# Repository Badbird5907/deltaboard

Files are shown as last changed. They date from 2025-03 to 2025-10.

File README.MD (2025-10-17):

# Deltaboard

Deltaboard is a TKL mechanical keyboard, directly using the [Keychron K8](https://www.keychron.com/products/keychron-k8-tenkeyless-wireless-mechanical-keyboard) as inspiration.
The hardest part building this project was routing all the switches and components for the RP2040.

[3D Render](https://autode.sk/4qxmMjt)

## Features:
- TKL Layout
- Kailh MX hotswap sockets
- OLED display
- Integrated RP2040
- USB-C
- RGB lighting
- EC11 Encoder
- QMK/VIA firmware

## Screenshots

### Schematic
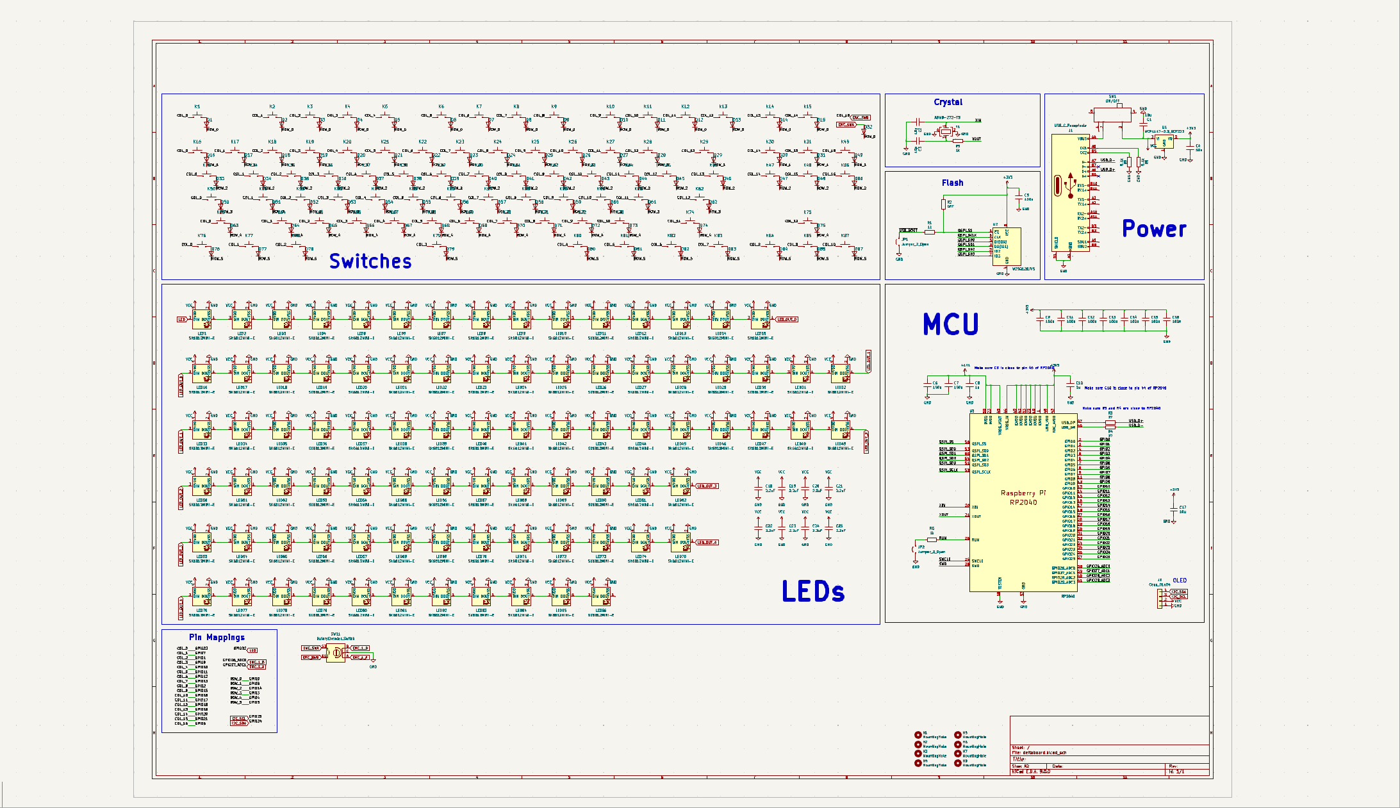
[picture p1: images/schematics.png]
Schematic


### PCB
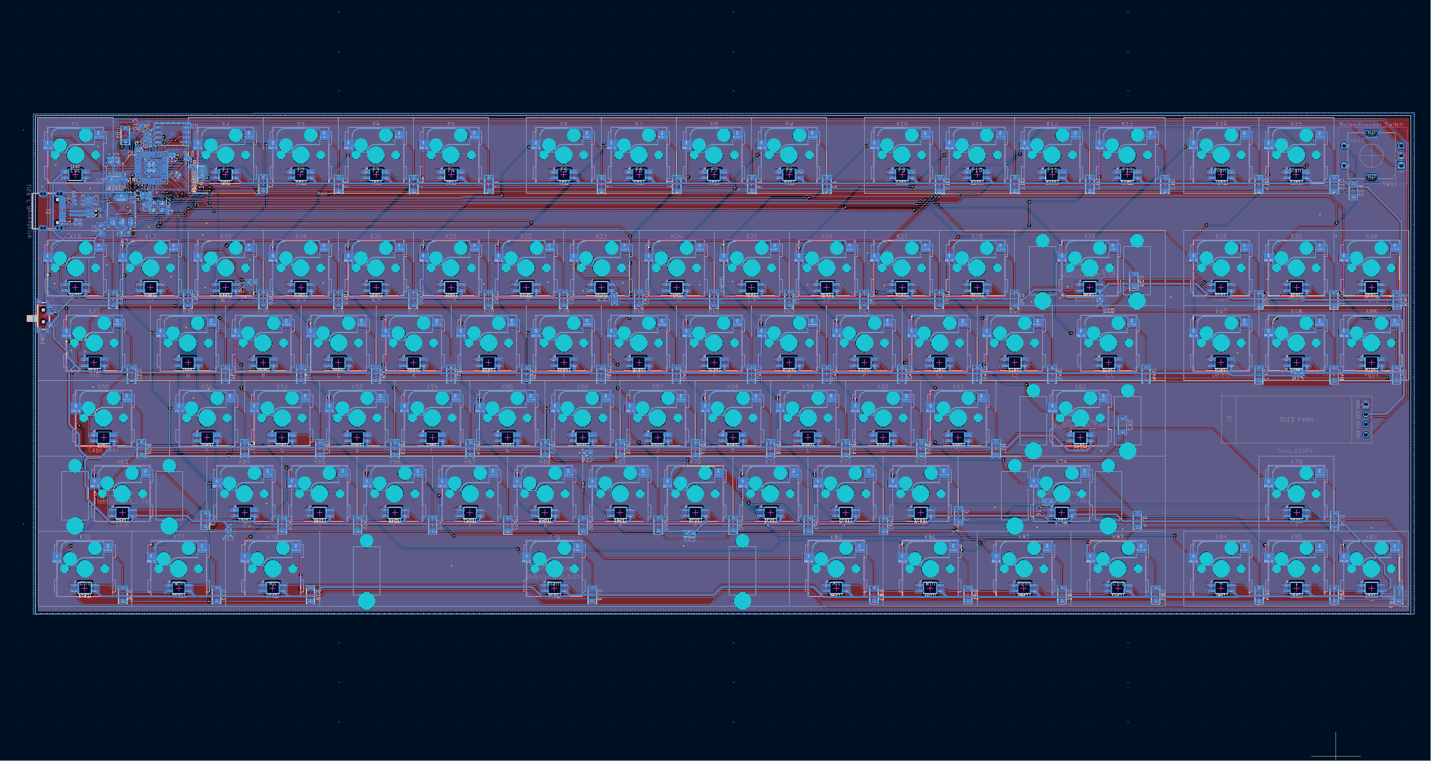
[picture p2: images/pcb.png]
PCB


### Front
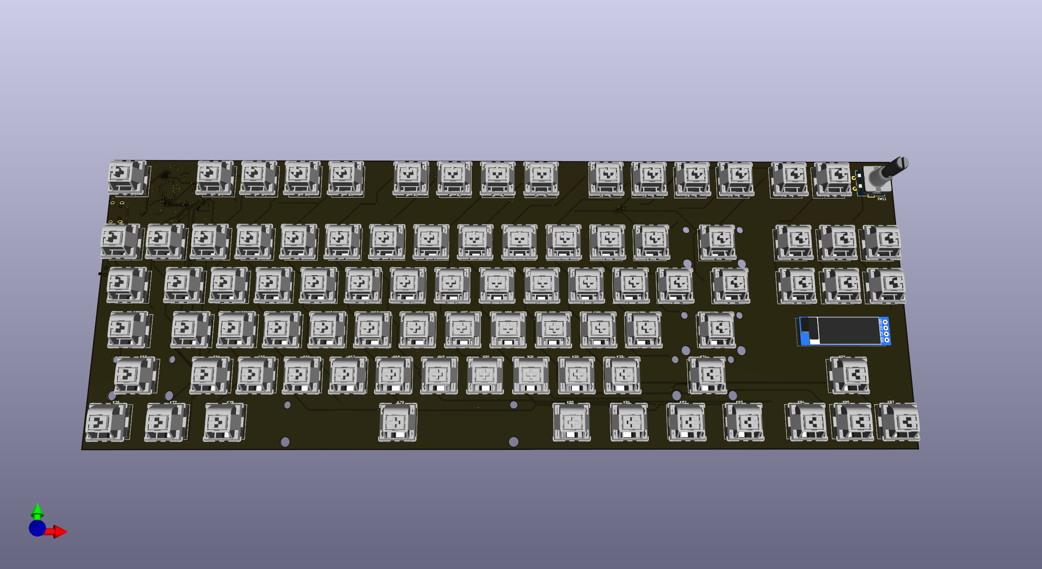
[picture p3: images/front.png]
Front


### Back
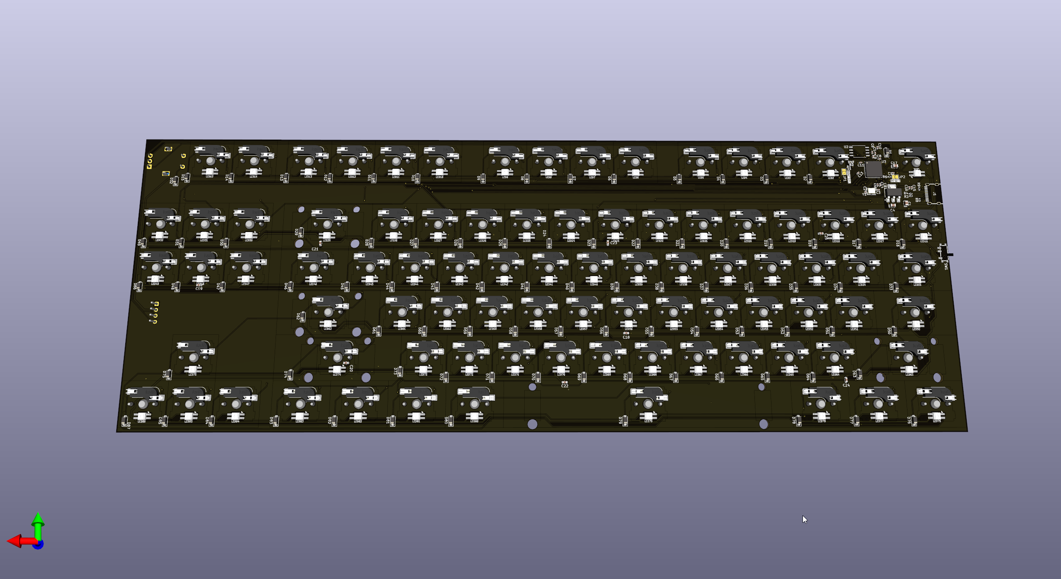
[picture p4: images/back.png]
Back


### Case
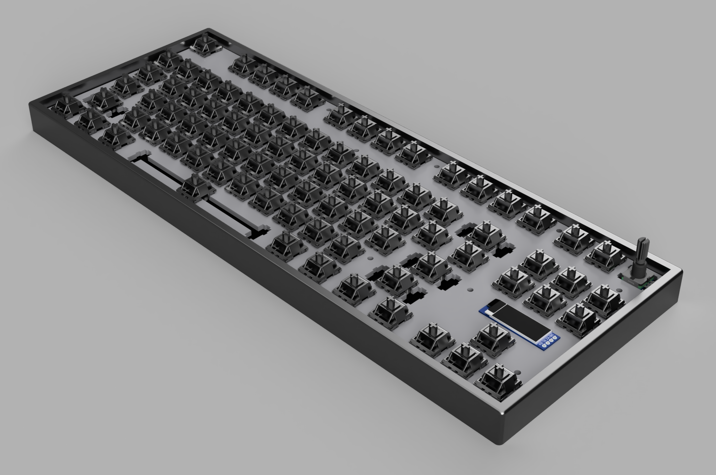
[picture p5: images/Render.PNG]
Case


**Note:** 6mm standoffs are used to keep the keyboard properly fastened to the case. (The height of kailh hotswap sockets are around 5.5mm)

## BOM

| Name | Quantity | $ Total (USD) | Notes | Links |
|---|---|---|---|---|
| Cherry MX2A Brown RGB | 84 | $35.92 | 90x, Free shipping (0.42c/switch) | [Aliexpress](https://www.aliexpress.com/item/1005007917791662.html) |
| DUROCK Stabilizer | 1 | $8.74 | V3 BS 4x2u 1x6.25u | [Aliexpress](https://www.aliexpress.com/item/1005006528731543.html) |
| M3 Heat Insert | 1 | $2.39 | 50x, Free shipping | [Aliexpress](https://www.aliexpress.com/item/1005003582355741.html) |
| M3 Standoffs (6mm) | 1 | $2.02 | 50x, Free shipping | [Aliexpress](https://www.aliexpress.com/item/32539100523.html?spm=a2g0o.productlist.0.0.3351234eJmAx93) |
| M3 Screws (6mm) | 1 | $1.94 | 50x, Free shipping | [Aliexpress](https://www.aliexpress.com/item/4001199728978.html) |
| Wormier Pudding Keycaps | 1 | $17.91 | | [Amazon](https://www.amazon.ca/XVX-Keycaps-Universal-Compatiability-Keyboard/) |
| Kailh MX Hotswap Sockets  | 90 | $11.35 | 50x + 30x + 10x, Free shipping | [Aliexpress](https://www.aliexpress.com/item/1005007225352311.html) |
| I2C OLED Display (0.91")  | 1 | $2.25 | Free shipping | [Aliexpress](https://www.aliexpress.com/item/1005005301005280.html) |
| EC11 Rotary Encoders | 1 | $3.40 | 20mm Half Handle, Free shipping | [Aliexpress](https://www.aliexpress.com/item/1005004907970664.html) |
| Encoder Cap | 1 | $2.23 | Half Handle Lid, Free shipping | [Aliexpress](https://www.aliexpress.com/item/1005004907970664.html) |
| LCSC Parts | 1 | $27.33 | $12.47 total, $3 handling fee, $11.86 shipping. Covers MCU, diodes, LEDs | [BOM](https://github.com/Badbird5907/deltaboard/blob/master/Production/PCB/BOM-deltaboard.csv) |
| PCB | 1 | $35.93 | $20.70 PCB + $15.23 shipping | |
**TOTAL: 151.41 USD**

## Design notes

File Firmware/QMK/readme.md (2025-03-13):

# deltaboard

deltaboard

*A short description of the keyboard/project*

* Keyboard Maintainer: [Evan Yu](https://github.com/Badbird5907)
* Hardware Supported: *The PCBs, controllers supported*
* Hardware Availability: *Links to where you can find this hardware*

Make example for this keyboard (after setting up your build environment):

    make deltaboard:default

Flashing example for this keyboard:

    make deltaboard:default:flash

See the [build environment setup](https://docs.qmk.fm/#/getting_started_build_tools) and the [make instructions](https://docs.qmk.fm/#/getting_started_make_guide) for more information. Brand new to QMK? Start with our [Complete Newbs Guide](https://docs.qmk.fm/#/newbs).

## Bootloader

Enter the bootloader in 3 ways:

* **Bootmagic reset**: Hold down the key at (0,0) in the matrix (usually the top left key or Escape) and plug in the keyboard
* **Physical reset button**: Briefly press the button on the back of the PCB - some may have pads you must short instead
* **Keycode in layout**: Press the key mapped to `QK_BOOT` if it is available

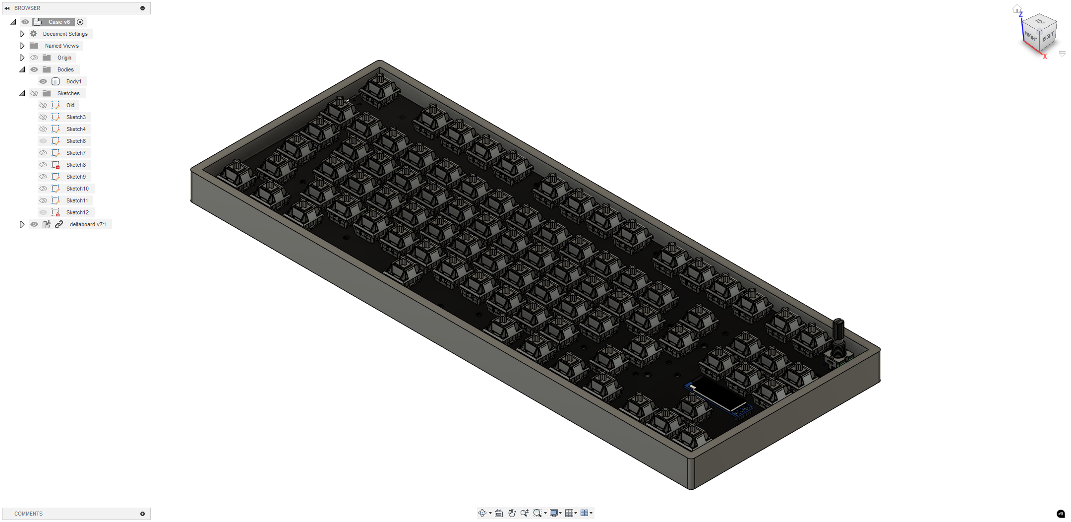
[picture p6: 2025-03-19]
images/case.png

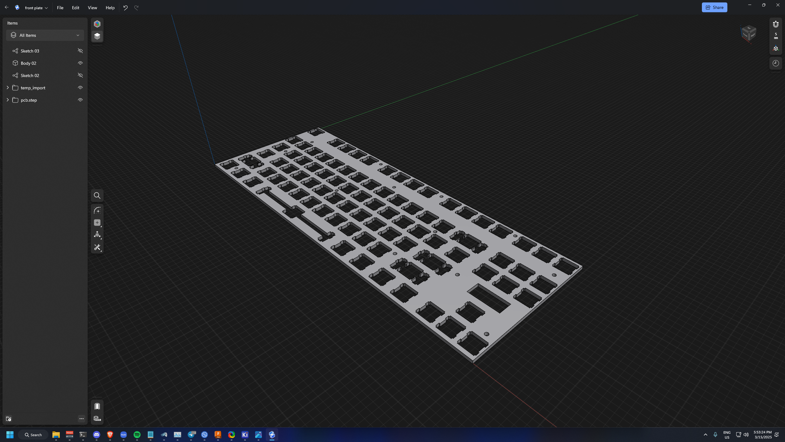
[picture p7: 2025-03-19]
images/NVIDIA_Overlay_wX2oQ0G0pX.png

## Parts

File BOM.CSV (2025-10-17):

Name | Quantity | $ Total (USD) | Notes | Links
Cherry MX2A Brown RGB | 84 | $35.92 | 90x, Free shipping (0.42c/switch) | https://www.aliexpress.com/item/1005007917791662.html
DUROCK Stabilizer | 1 | $8.74 | V3 BS 4x2u 1x6.25u | https://www.aliexpress.com/item/1005006528731543.html
M3 Heat Insert | 1 | $2.39 | 50x, Free shipping | https://www.aliexpress.com/item/1005003582355741.html
M3 Standoffs (6mm) | 1 | $2.02 | 50x, Free shipping | https://www.aliexpress.com/item/32539100523.html
M3 Screws (6mm) | 1 | $1.94 | 50x, Free shipping | https://www.aliexpress.com/item/4001199728978.html
Wormier Pudding Keycaps | 1 | $17.91 |  | https://www.amazon.ca/XVX-Keycaps-Universal-Compatiability-Keyboard/
Kailh MX Hotswap Sockets | 90 | $11.35 | 50x + 30x + 10x, Free shipping | https://www.aliexpress.com/item/1005007225352311.html
I2C OLED Display (0.91") | 1 | $2.25 | Free shipping | https://www.aliexpress.com/item/1005005301005280.html
EC11 Rotary Encoders | 1 | $3.40 | 20mm Half Handle, Free shipping | https://www.aliexpress.com/item/1005004907970664.html
Encoder Cap | 1 | $2.23 | Half Handle Lid, Free shipping | https://www.aliexpress.com/item/1005004907970664.html
LCSC Parts | 1 | $27.33 | $12.47 total, $3 handling fee, $11.86 shipping. This covers both MCU and diodes / leds. | https://github.com/Badbird5907/deltaboard/blob/master/Production/PCB/BOM-deltaboard.csv
PCB | 1 | 35.93 | 20.70 pcb + 15.23 shipping

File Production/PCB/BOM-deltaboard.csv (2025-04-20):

Comment | Designator | Footprint | LCSC | Quantity
1k | R1,R5,R6 | R_0402_1005Metric | C11702 | 3
100n | C11,C12,C13,C14,C15,C16,C5,C6,C7,C9 | C_0402_1005Metric | C1525 | 10
15p | C2,C3 | C_0402_1005Metric | C1548 | 2
10u | C1,C17,C4 | C_0805_2012Metric | C15850 | 3
RP2040 | U3 | RP2040-QFN-56 | C2040 | 1
ABM8-272-T3 | Y1 | Crystal_SMD_3225-4Pin_3.2x2.5mm | C20625731 | 1
2.2uF | C18,C19,C20,C21,C22,C23,C24,C25 | C_0603_1608Metric | C23630 | 8
27 | R3,R4 | R_0402_1005Metric | C25100 | 2
5.1k | R8,R9 | R_0402_1005Metric | C25905 | 2
NCP1117-3.3_SOT223 | U1 | SOT-223-3_TabPin2 | C26537 | 1
SK6812MINI-E | LED1,LED10,LED11,LED12,LED13,LED14,LED15,LED16,LED17,LED18,LED19,LED2,LED20,LED21,LED22,LED23,LED24,LED25,LED26,LED27,LED28,LED29,LED3,LED30,LED31,LED32,LED33,LED34,LED35,LED36,LED37,LED38,LED39,LED4,LED40,LED41,LED42,LED43,LED44,LED45,LED46,LED47,LED48,LED49,LED5,LED50,LED51,LED52,LED53,LED54,LED55,LED56,LED57,LED58,LED59,LED6,LED60,LED61,LED62,LED63,LED64,LED65,LED66,LED67,LED68,LED69,LED7,LED70,LED71,LED72,LED73,LED74,LED75,LED76,LED77,LED78,LED79,LED8,LED80,LED81,LED82,LED83,LED84,LED85,LED86,LED9 | SK6812MINI-E | C5149201 | 86
1u | C10,C8 | C_0402_1005Metric | C52923 | 2
USB_C_Receptacle | J1,SW1 | USB-C_SMD-TYPE-C-31-M-12 | C7498220 | 2
D | D1,D10,D11,D12,D13,D14,D15,D16,D17,D18,D19,D2,D20,D21,D22,D23,D24,D25,D26,D27,D28,D29,D3,D30,D31,D32,D33,D34,D35,D36,D37,D38,D39,D4,D40,D41,D42,D43,D44,D45,D46,D47,D48,D49,D5,D50,D51,D52,D53,D54,D55,D56,D57,D58,D59,D6,D60,D61,D62,D63,D64,D65,D66,D67,D68,D69,D7,D70,D71,D72,D73,D74,D75,D76,D77,D78,D79,D8,D80,D81,D82,D83,D84,D85,D86,D87,D9 | D_SOD-123 | C81598 | 87
W25Q128JVS | U2 | SOIC-8_5.23x5.23mm_P1.27mm | C97521 | 1
F4 | K5 | Hotswap_MX_1.00u |  | 1
A | K51 | Hotswap_MX_1.00u |  | 1
F | K54 | Hotswap_MX_1.00u |  | 1
",' | K61 | Hotswap_MX_1.00u |  | 1
C | K66 | Hotswap_MX_1.00u |  | 1
&,7 | K23 | Hotswap_MX_1.00u |  | 1
H | K56 | Hotswap_MX_1.00u |  | 1
Caps Lock | K50 | Hotswap_MX_1.75u |  | 1
Z | K64 | Hotswap_MX_1.00u |  | 1
X | K65 | Hotswap_MX_1.00u |  | 1
V | K67 | Hotswap_MX_1.00u |  | 1
%,5 | K21 | Hotswap_MX_1.00u |  | 1
S | K52 | Hotswap_MX_1.00u |  | 1
Shift | K63 | Hotswap_MX_2.25u |  | 1
Ctrl | K76 | Hotswap_MX_1.25u |  | 1
R | K37 | Hotswap_MX_1.00u |  | 1
Alt | K78 | Hotswap_MX_1.25u |  | 1
Blank | K15 | Hotswap_MX_1.00u |  | 1
Shift | K74 | Hotswap_MX_2.75u |  | 1
Conn_01x04 | J2 | SSD1306-0.91-OLED-4pin-128x32 |  | 1
Delete | K47 | Hotswap_MX_1.00u |  | 1
MountingHole | H6 | MountingHole_3.2mm_M3 |  | 1
Blank | K14 | Hotswap_MX_1.00u |  | 1
MountingHole | H1 | MountingHole_3.2mm_M3 |  | 1
F6 | K7 | Hotswap_MX_1.00u |  | 1
MountingHole | H10 | MountingHole_3.2mm_M3 |  | 1
@,2 | K18 | Hotswap_MX_1.00u |  | 1
!,1 | K17 | Hotswap_MX_1.00u |  | 1
M | K70 | Hotswap_MX_1.00u |  | 1
Esc | K1 | Hotswap_MX_1.00u |  | 1
Y | K39 | Hotswap_MX_1.00u |  | 1
MountingHole | H14 | MountingHole_3.2mm_M3 |  | 1
F8 | K9 | Hotswap_MX_1.00u |  | 1
P | K43 | Hotswap_MX_1.00u |  | 1
RotaryEncoder_Switch | SW11 | encoder |  | 1
F1 | K2 | Hotswap_MX_1.00u |  | 1
|,\ | K46 | Hotswap_MX_1.50u |  | 1
O | K42 | Hotswap_MX_1.00u |  | 1
_,- | K27 | Hotswap_MX_1.00u |  | 1
MountingHole | H2 | MountingHole_3.2mm_M3 |  | 1
+,= | K28 | Hotswap_MX_1.00u |  | 1
Q | K34 | Hotswap_MX_1.00u |  | 1
E | K36 | Hotswap_MX_1.00u |  | 1
G | K55 | Hotswap_MX_1.00u |  | 1
),0 | K26 | Hotswap_MX_1.00u |  | 1
PgUp | K49 | Hotswap_MX_1.00u |  | 1
},] | K45 | Hotswap_MX_1.00u |  | 1
Insert | K30 | Hotswap_MX_1.00u |  | 1
I | K41 | Hotswap_MX_1.00u |  | 1
F10 | K11 | Hotswap_MX_1.00u |  | 1
Alt | K80 | Hotswap_MX_1.25u |  | 1
F3 | K4 | Hotswap_MX_1.00u |  | 1
K | K58 | Hotswap_MX_1.00u |  | 1
MountingHole | H3 | MountingHole_3.2mm_M3 |  | 1
F7 | K8 | Hotswap_MX_1.00u |  | 1
W | K35 | Hotswap_MX_1.00u |  | 1
>,. | K72 | Hotswap_MX_1.00u |  | 1
F11 | K12 | Hotswap_MX_1.00u |  | 1
MountingHole | H5 | MountingHole_3.2mm_M3 |  | 1
~~,` | K16 | Hotswap_MX_1.00u |  | 1
<,, | K71 | Hotswap_MX_1.00u |  | 1
Home | K31 | Hotswap_MX_1.00u |  | 1
MountingHole | H7 | MountingHole_3.2mm_M3 |  | 1
Tab | K33 | Hotswap_MX_1.50u |  | 1
MountingHole | H12 | MountingHole_3.2mm_M3 |  | 1
PgDn | K86 | Hotswap_MX_1.00u |  | 1
N | K69 | Hotswap_MX_1.00u |  | 1
MountingHole | H4 | MountingHole_3.2mm_M3 |  | 1
F2 | K3 | Hotswap_MX_1.00u |  | 1
^,6 | K22 | Hotswap_MX_1.00u |  | 1
F12 | K13 | Hotswap_MX_1.00u |  | 1
MountingHole | H9 | MountingHole_3.2mm_M3 |  | 1
Backspace | K29 | Hotswap_MX_2.00u |  | 1
$,4 | K20 | Hotswap_MX_1.00u |  | 1
#,3 | K19 | Hotswap_MX_1.00u |  | 1
MountingHole | H11 | MountingHole_3.2mm_M3 |  | 1
D | K53 | Hotswap_MX_1.00u |  | 1
?,/ | K73 | Hotswap_MX_1.00u |  | 1
MountingHole | H13 | MountingHole_3.2mm_M3 |  | 1
(,9 | K25 | Hotswap_MX_1.00u |  | 1
End | K48 | Hotswap_MX_1.00u |  | 1
Ctrl | K83 | Hotswap_MX_1.25u |  | 1
← | K84 | Hotswap_MX_1.00u |  | 1
J | K57 | Hotswap_MX_1.00u |  | 1
Win | K77 | Hotswap_MX_1.25u |  | 1
Enter | K62 | Hotswap_MX_2.25u |  | 1
Blank | K79 | Hotswap_MX_6.25u |  | 1
:,; | K60 | Hotswap_MX_1.00u |  | 1
↑ | K75 | Hotswap_MX_1.00u |  | 1
T | K38 | Hotswap_MX_1.00u |  | 1
F5 | K6 | Hotswap_MX_1.00u |  | 1
{,[ | K44 | Hotswap_MX_1.00u |  | 1
B | K68 | Hotswap_MX_1.00u |  | 1
F9 | K10 | Hotswap_MX_1.00u |  | 1
Win | K81 | Hotswap_MX_1.25u |  | 1
L | K59 | Hotswap_MX_1.00u |  | 1
Menu | K82 | Hotswap_MX_1.25u |  | 1
U | K40 | Hotswap_MX_1.00u |  | 1
*,8 | K24 | Hotswap_MX_1.00u |  | 1
→ | K87 | Hotswap_MX_1.00u |  | 1
MountingHole | H8 | MountingHole_3.2mm_M3 |  | 1
↓ | K85 | Hotswap_MX_1.00u |  | 1
Jumper_2_Open | JP1 | SolderJumper-2_P1.3mm_Open_TrianglePad1.0x1.5mm |  | 1
Jumper_2_Open | JP2 | SolderJumper-2_P1.3mm_Open_TrianglePad1.0x1.5mm |  | 1
DNF | R2 | R_0402_1005Metric |  | 1
10k | R7 | R_0805_2012Metric |  | 1
10k | R10 | R_0805_2012Metric |  | 1

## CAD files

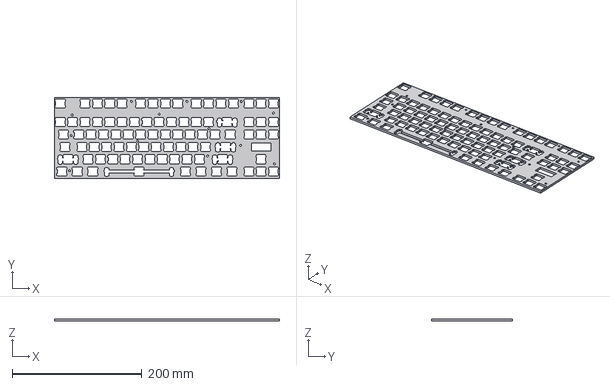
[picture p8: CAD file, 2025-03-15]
CAD/front plate.step
346.6 x 124.3 x 3.00 mm
temp_import
deltaboard_PCB

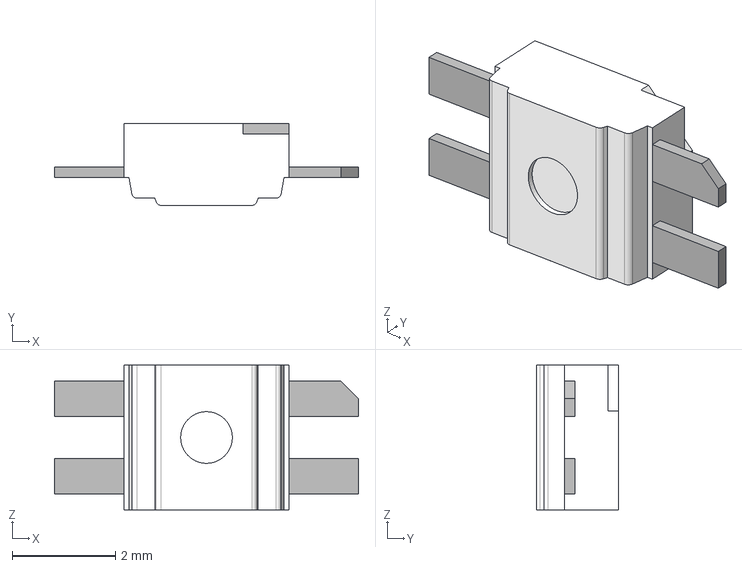
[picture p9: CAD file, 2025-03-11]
PCB/Components/neopixel.petty/SK6812MINI-E.step
5.88 x 1.58 x 2.80 mm

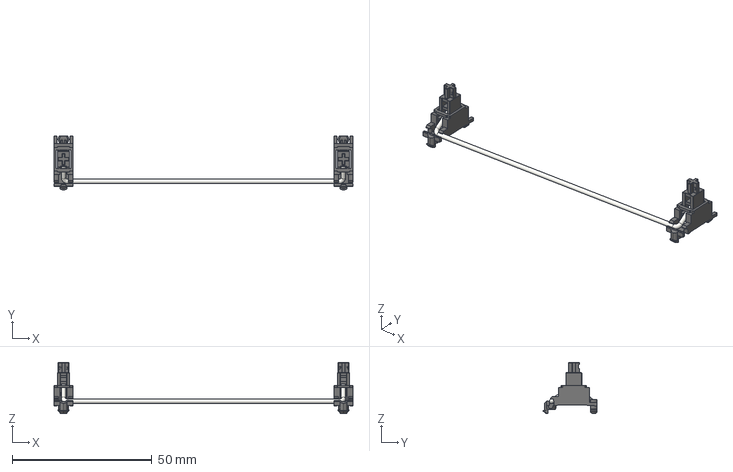
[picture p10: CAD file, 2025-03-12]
PCB/Components/stabalizers/Stabilizer_MX_6.25u.step
106.8 x 19.2 x 18.3 mm

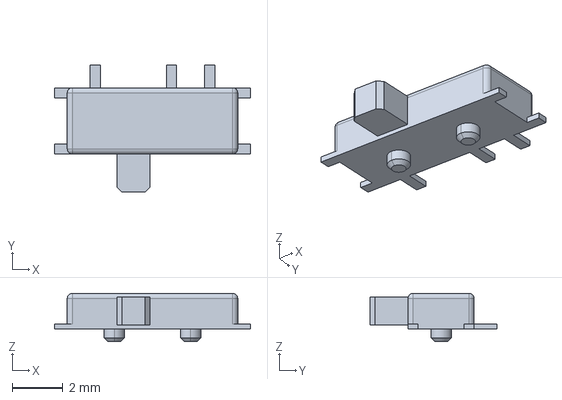
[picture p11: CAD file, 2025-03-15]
PCB/Components/switch_kps-1290.stp
7.70 x 5.00 x 1.90 mm

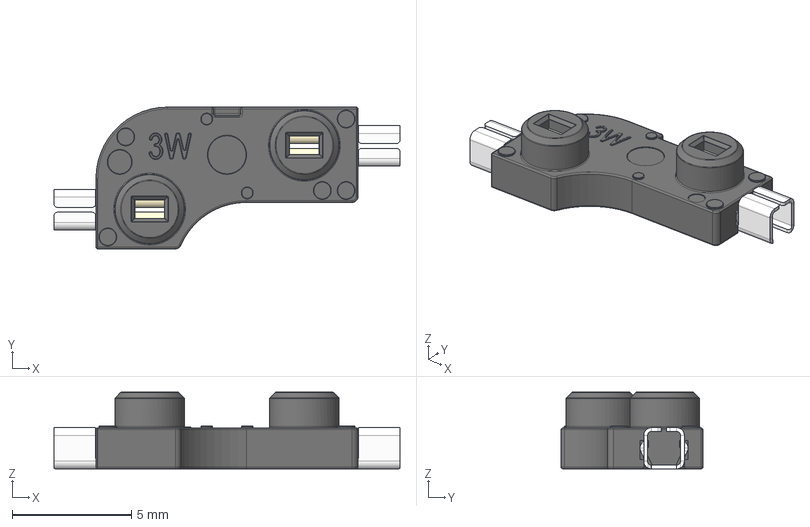
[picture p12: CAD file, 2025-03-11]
PCB/Components/switches/Hotswap_MX.step
14.5 x 5.95 x 3.22 mm

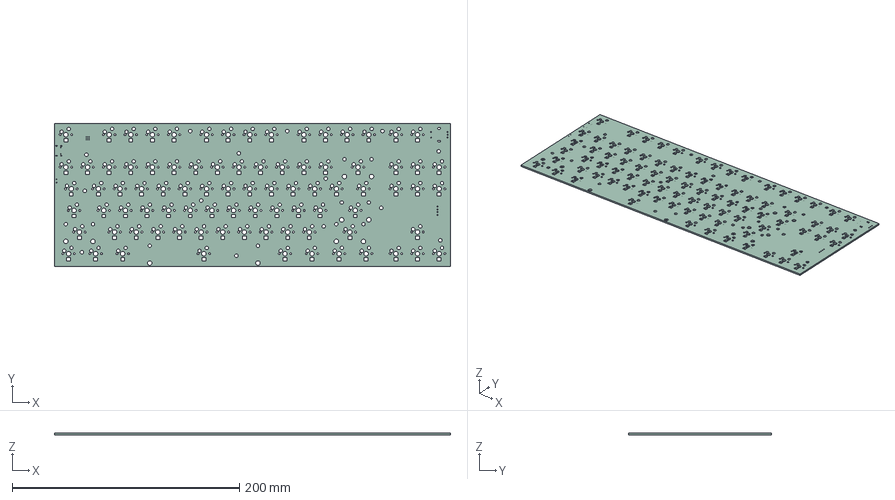
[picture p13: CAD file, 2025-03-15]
PCB/pcb.step
348.6 x 126.3 x 1.51 mm

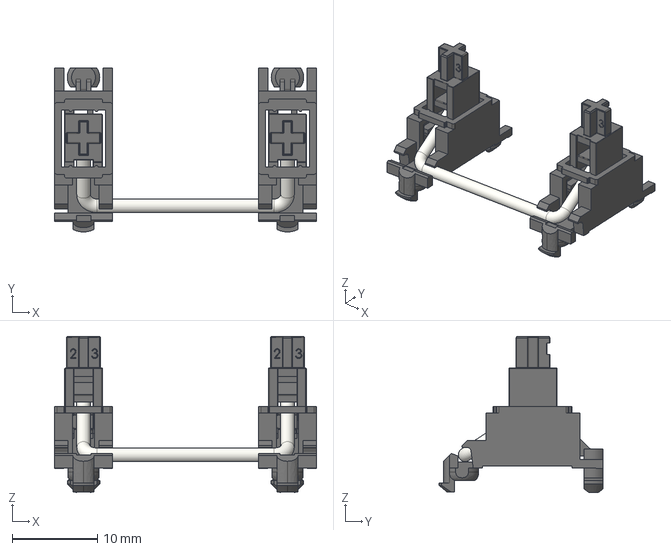
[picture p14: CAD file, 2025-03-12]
PCB/Components/stabalizers/Stabilizer_MX_2.00u.step
30.7 x 19.2 x 18.3 mm

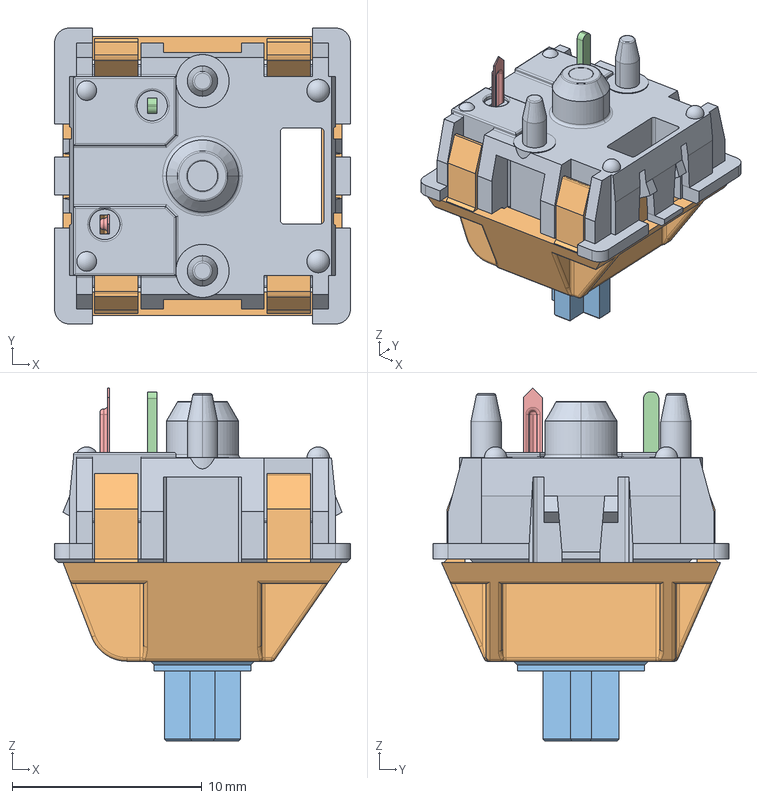
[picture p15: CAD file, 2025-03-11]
PCB/Components/switches/CherryMX.stp
15.6 x 15.6 x 18.6 mm
MX_DOWN
MX_UP
UP_MX
MX_PIN
MX_SPRING
MX_CLICK

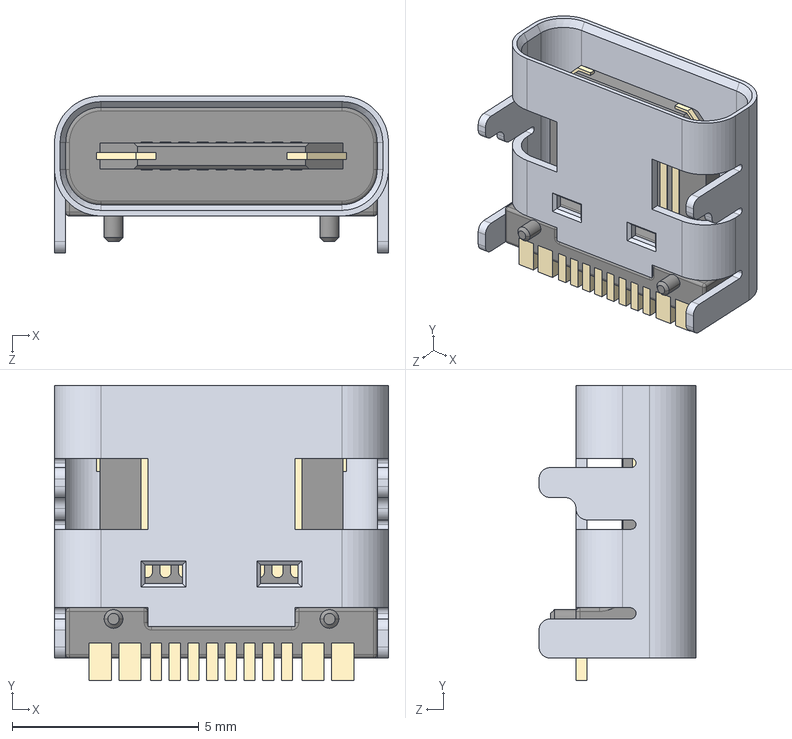
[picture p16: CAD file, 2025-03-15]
PCB/Components/usbc.step
8.94 x 7.90 x 4.20 mm

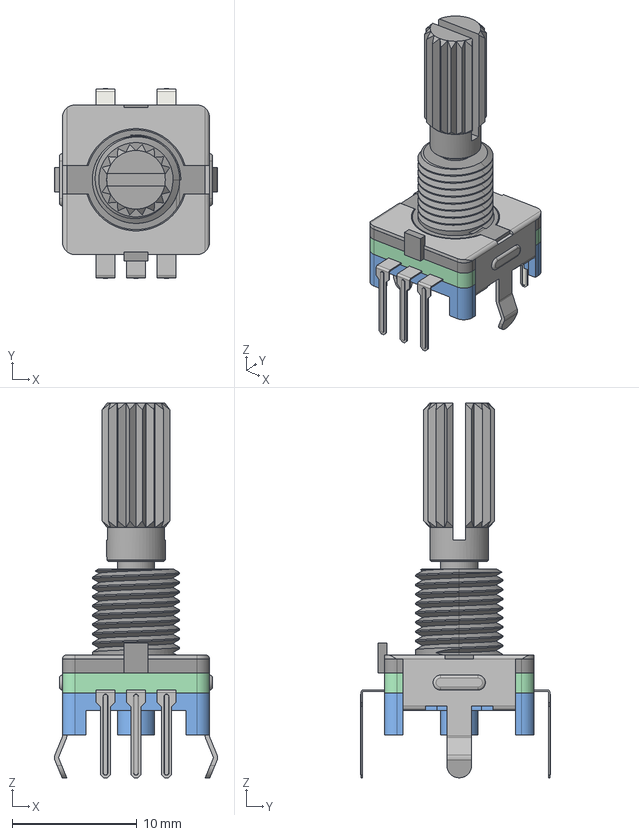
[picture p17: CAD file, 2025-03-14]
PCB/Components/EC11_Rotary_Encoder_Switched.step
13.1 x 15.3 x 30.1 mm

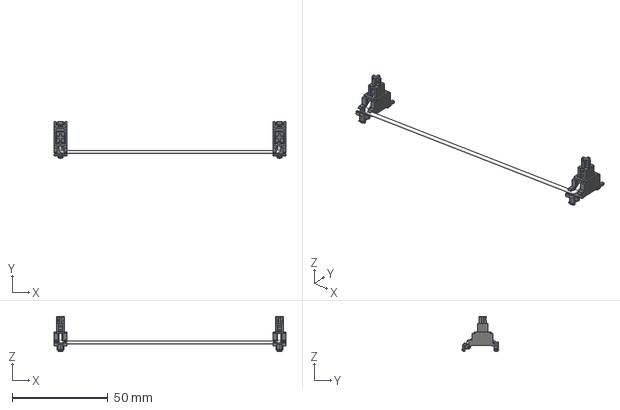
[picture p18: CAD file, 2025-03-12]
PCB/Components/stabalizers/Stabilizer_MX_7.00u.step
121.1 x 19.2 x 18.3 mm

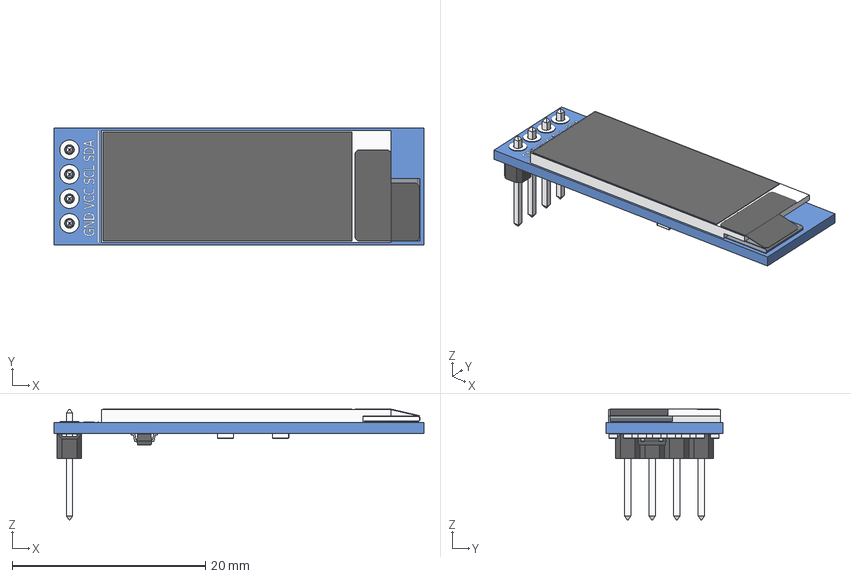
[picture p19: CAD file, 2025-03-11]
PCB/Components/OLED_0.91_128x32.stp
38.3 x 12.1 x 11.5 mm
OLED_0.91_128x32
Pin Header 4 x 1 TH 2.54mm Pitch
RESC-0603 x 13
2SD0601A

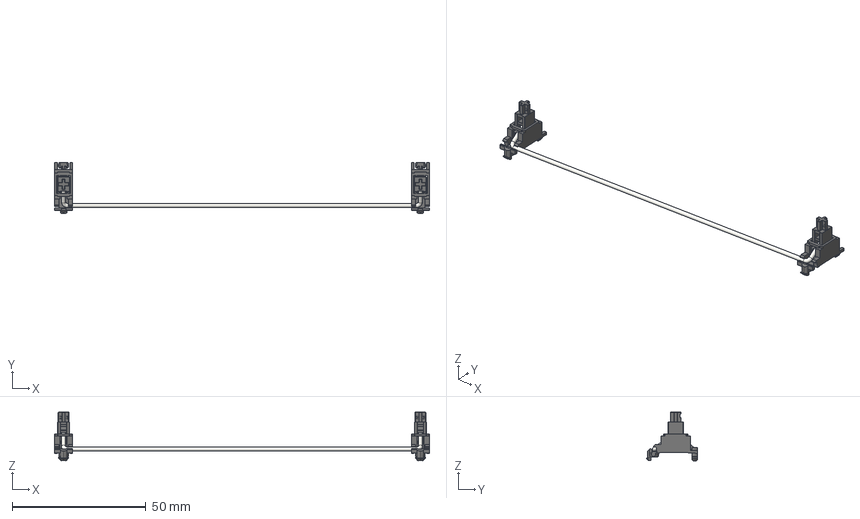
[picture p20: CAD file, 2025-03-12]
PCB/Components/stabalizers/Stabilizer_MX_8.00u.step
140.1 x 19.2 x 18.3 mm

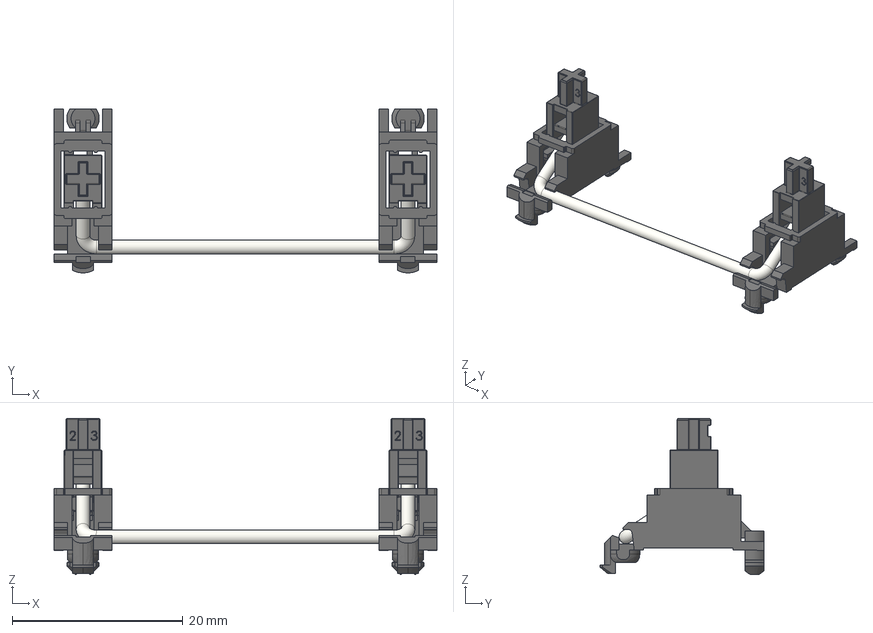
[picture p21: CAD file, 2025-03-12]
PCB/Components/stabalizers/Stabilizer_MX_3.00u.step
44.9 x 19.2 x 18.3 mm

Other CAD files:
PCB/Components/stabalizers/Stabilizer_MX_6.00u.step

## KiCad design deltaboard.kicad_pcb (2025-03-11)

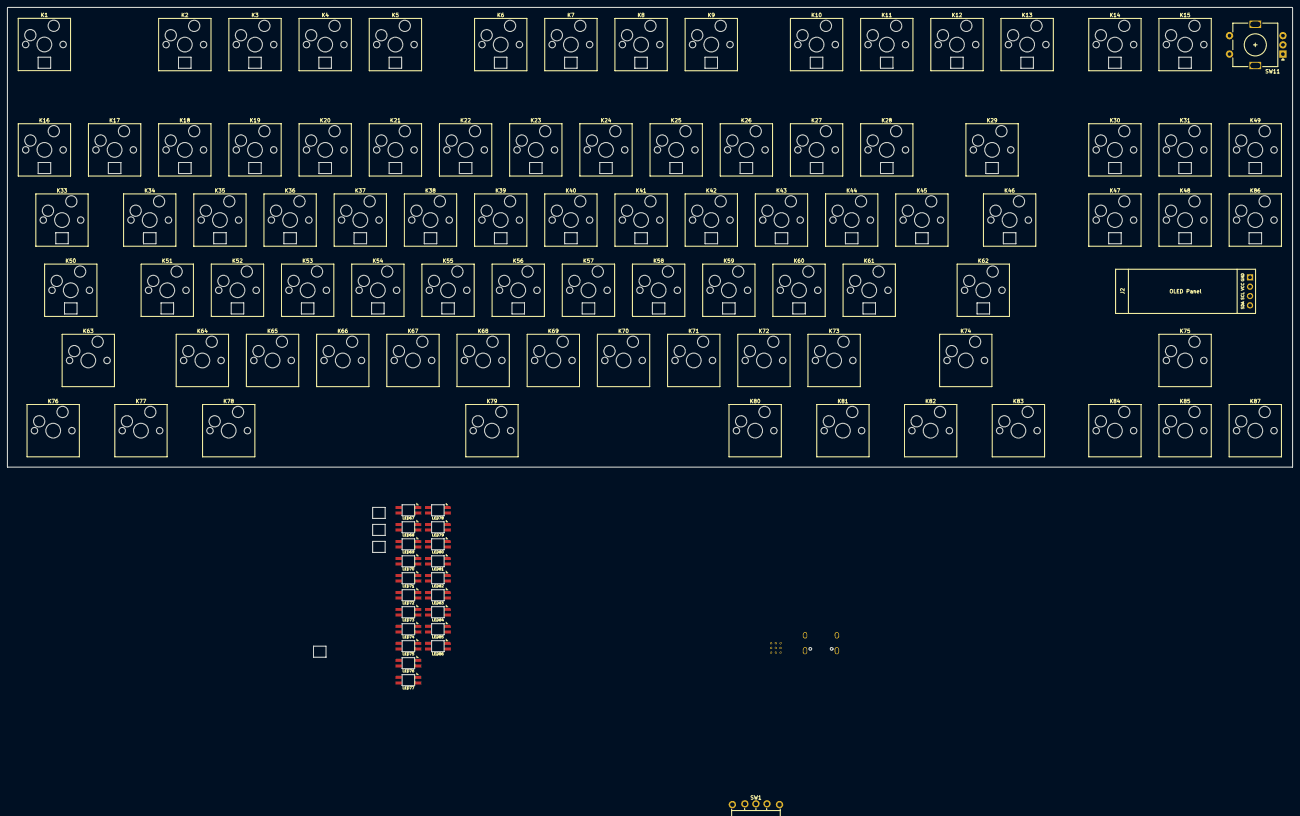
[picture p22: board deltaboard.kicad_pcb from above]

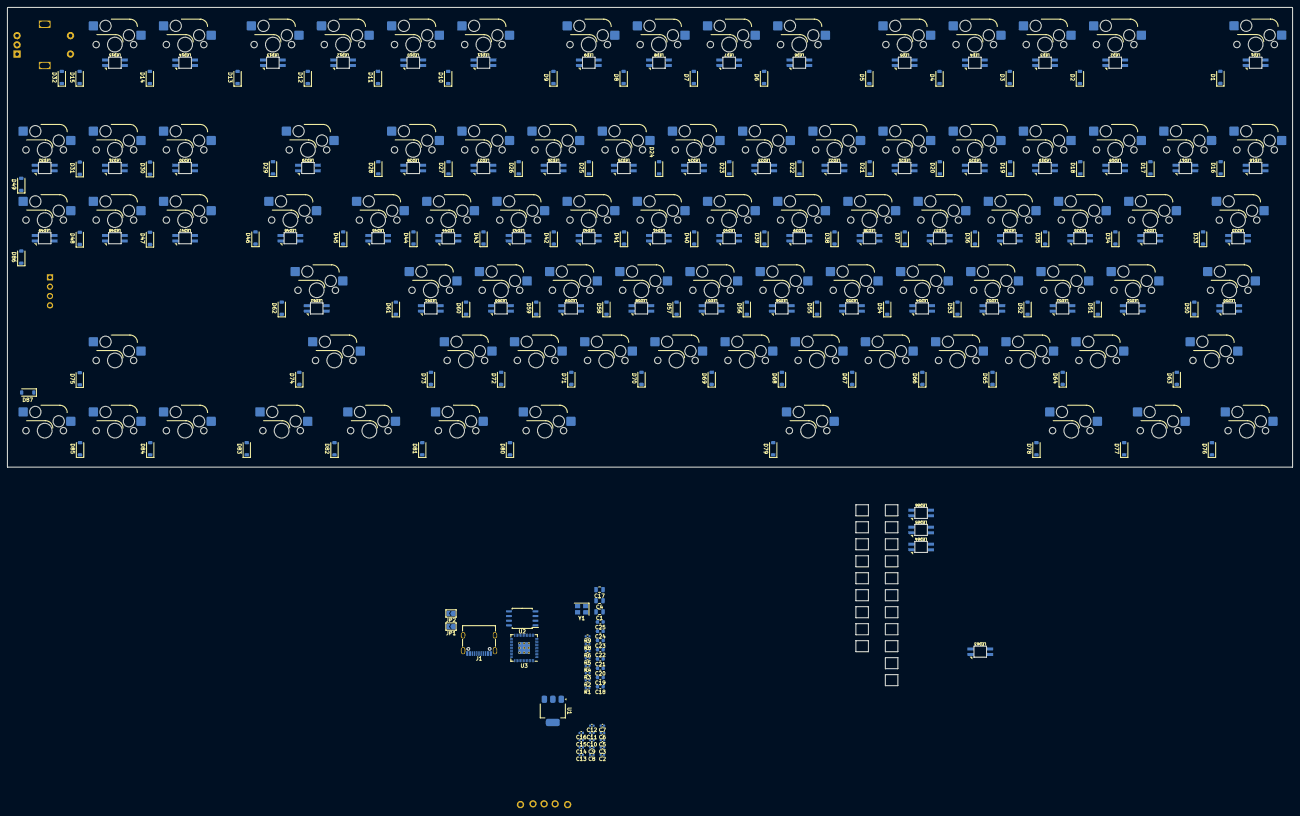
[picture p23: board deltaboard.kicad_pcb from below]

Board: 2 copper layers, 348.8 x 184.1 mm, 310 parts (193 on the bottom side), 224 nets, no tracks yet.

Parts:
C1, C4, C17: 10u; C_0805_2012Metric
C2, C3: 15p; C_0402_1005Metric
C5, C6, C7, C9, C11, C12, C13, C14, C15, C16: 100n; C_0402_1005Metric
C8, C10: 1u; C_0402_1005Metric
C18, C19, C20, C21, C22, C23, C24, C25: 2.2uF; C_0603_1608Metric
D1, D2, D3, D4, D5, D6, D7, D8, D9, D10, D11, D12, D13, D14, D15, D16, D17, D18, D19, D20, D21, D22, D23, D24, D25, D26, D27, D28, D29, D30, D31, D32, D33, D34, D35, D36, D37, D38, D39, D40, D41, D42, D43, D44, D45, D46, D47, D48, D49, D50, D51, D52, D53, D54, D55, D56, D57, D58, D59, D60, D61, D62, D63, D64, D65, D66, D67, D68, D69, D70, D71, D72, D73, D74, D75, D76, D77, D78, D79, D80, D81, D82, D83, D84, D85, D86, D87: D; D_SOD-123
H1, H2, H3, H4, H5, H6, H7, H8: MountingHole; MountingHole_2.7mm_M2.5
J1: USB_C_Receptacle; USB-C_SMD-TYPE-C-31-M-12
J2: Conn_01x04; SSD1306-0.91-OLED-4pin-128x32
JP1, JP2: Jumper_2_Open; SolderJumper-2_P1.3mm_Open_TrianglePad1.0x1.5mm
K1: Esc; Hotswap_MX_1.00u
K2: F1; Hotswap_MX_1.00u
K3: F2; Hotswap_MX_1.00u
K4: F3; Hotswap_MX_1.00u
K5: F4; Hotswap_MX_1.00u
K6: F5; Hotswap_MX_1.00u
K7: F6; Hotswap_MX_1.00u
K8: F7; Hotswap_MX_1.00u
K9: F8; Hotswap_MX_1.00u
K10: F9; Hotswap_MX_1.00u
K11: F10; Hotswap_MX_1.00u
K12: F11; Hotswap_MX_1.00u
K13: F12; Hotswap_MX_1.00u
K14, K15: Blank; Hotswap_MX_1.00u
K16: ~~,`; Hotswap_MX_1.00u
K17: !,1; Hotswap_MX_1.00u
K18: @,2; Hotswap_MX_1.00u
K19: #,3; Hotswap_MX_1.00u
K20: $,4; Hotswap_MX_1.00u
K21: %,5; Hotswap_MX_1.00u
K22: ^,6; Hotswap_MX_1.00u
K23: &,7; Hotswap_MX_1.00u
K24: *,8; Hotswap_MX_1.00u
K25: (,9; Hotswap_MX_1.00u
K26: ),0; Hotswap_MX_1.00u
K27: _,-; Hotswap_MX_1.00u
K28: +,=; Hotswap_MX_1.00u
K29: Backspace; Hotswap_MX_2.00u
K30: Insert; Hotswap_MX_1.00u
K31: Home; Hotswap_MX_1.00u
K33: Tab; Hotswap_MX_1.50u
K34: Q; Hotswap_MX_1.00u
K35: W; Hotswap_MX_1.00u
K36: E; Hotswap_MX_1.00u
K37: R; Hotswap_MX_1.00u
K38: T; Hotswap_MX_1.00u
K39: Y; Hotswap_MX_1.00u
K40: U; Hotswap_MX_1.00u
K41: I; Hotswap_MX_1.00u
K42: O; Hotswap_MX_1.00u
K43: P; Hotswap_MX_1.00u
K44: {,[; Hotswap_MX_1.00u
K45: },]; Hotswap_MX_1.00u
K46: |,\; Hotswap_MX_1.50u
K47: Delete; Hotswap_MX_1.00u
K48: End; Hotswap_MX_1.00u
K49: PgUp; Hotswap_MX_1.00u
K50: Caps Lock; Hotswap_MX_1.75u
K51: A; Hotswap_MX_1.00u
K52: S; Hotswap_MX_1.00u
K53: D; Hotswap_MX_1.00u
K54: F; Hotswap_MX_1.00u
K55: G; Hotswap_MX_1.00u
K56: H; Hotswap_MX_1.00u
K57: J; Hotswap_MX_1.00u
K58: K; Hotswap_MX_1.00u
K59: L; Hotswap_MX_1.00u
K60: :,;; Hotswap_MX_1.00u
K61: ",'; Hotswap_MX_1.00u
K62: Enter; Hotswap_MX_2.25u
K63: Shift; Hotswap_MX_2.25u
K64: Z; Hotswap_MX_1.00u
K65: X; Hotswap_MX_1.00u
K66: C; Hotswap_MX_1.00u
K67: V; Hotswap_MX_1.00u
K68: B; Hotswap_MX_1.00u
K69: N; Hotswap_MX_1.00u
K70: M; Hotswap_MX_1.00u
K71: <,,; Hotswap_MX_1.00u
K72: >,.; Hotswap_MX_1.00u
K73: ?,/; Hotswap_MX_1.00u
K74: Shift; Hotswap_MX_2.75u
K75: ↑; Hotswap_MX_1.00u
K76, K83: Ctrl; Hotswap_MX_1.25u
K77, K81: Win; Hotswap_MX_1.25u
K78, K80: Alt; Hotswap_MX_1.25u
K79: Blank; Hotswap_MX_6.25u
K82: Menu; Hotswap_MX_1.25u
K84: ←; Hotswap_MX_1.00u
K85: ↓; Hotswap_MX_1.00u
K86: PgDn; Hotswap_MX_1.00u
K87: →; Hotswap_MX_1.00u
LED1, LED2, LED3, LED4, LED5, LED6, LED7, LED8, LED9, LED10, LED11, LED12, LED13, LED14, LED15, LED16, LED17, LED18, LED19, LED20, LED21, LED22, LED23, LED24, LED25, LED26, LED27, LED28, LED29, LED30, LED31, LED32, LED33, LED34, LED35, LED36, LED37, LED38, LED39, LED40, LED41, LED42, LED43, LED44, LED45, LED46, LED47, LED48, LED49, LED50, LED51, LED52, LED53, LED54, LED55, LED56, LED57, LED58, LED59, LED60, LED61, LED62, LED63, LED64, LED65, LED66, LED67, LED68, LED69, LED70, LED71, LED72, LED73, LED74, LED75, LED76, LED77, LED78, LED79, LED80, LED81, LED82, LED83, LED84, LED85, LED86: SK6812-MINI-E; SK6812MINI-E
R1, R5, R6: 1k; R_0402_1005Metric
R2: DNF; R_0402_1005Metric
R3, R4: 27; R_0402_1005Metric
R8, R9: 5.1k; R_0402_1005Metric
SW1: SW_SPST; SW-TH_KH-SS12F23-G6
SW11: RotaryEncoder_Switch; encoder
U1: NCP1117-3.3_SOT223; SOT-223-3_TabPin2
U2: W25Q128JVS; SOIC-8_5.23x5.23mm_P1.27mm
U3: RP2040; RP2040-QFN-56
Y1: ABM8-272-T3; Crystal_SMD_3225-4Pin_3.2x2.5mm

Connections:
+1V1: C6.1, C7.1, C8.1, U3.23 (DVDD), U3.45 (VREG_VOUT), U3.50 (DVDD)
+3V3: C4.1, C5.1, C9.1, C10.1, C11.1, C12.1, C13.1, C14.1, C15.1, C16.1, C17.1, R2.1, U1.2 (VO), U2.8 (VCC), U3.1 (IOVDD), U3.10 (IOVDD), U3.22 (IOVDD), U3.33 (IOVDD), U3.42 (IOVDD), U3.43 (ADC_AVDD), U3.44 (VREG_IN), U3.48 (USB_VDD), U3.49 (IOVDD)
/COL_0: K1.1, K16.1, K33.1, K50.1, K63.1, K76.1, U3.8 (GPIO6)
/COL_1: K2.1, K17.1, K34.1, K51.1, K64.1, K77.1, U3.9 (GPIO7)
/COL_2: K3.1, K18.1, K35.1, K52.1, K65.1, K78.1, U3.11 (GPIO8)
/COL_3: K4.1, K19.1, K36.1, K53.1, K66.1, K79.1, U3.12 (GPIO9)
/COL_4: K5.1, K20.1, K37.1, K54.1, K67.1, K80.1, U3.13 (GPIO10)
/COL_5: K6.1, K21.1, K38.1, K55.1, K68.1, K81.1, U3.14 (GPIO11)
/COL_6: K7.1, K22.1, K39.1, K56.1, K69.1, K82.1, U3.15 (GPIO12)
/COL_7: K8.1, K23.1, K40.1, K57.1, K70.1, K83.1, U3.16 (GPIO13)
/COL_8: K9.1, K24.1, K41.1, K58.1, K71.1, K84.1, U3.17 (GPIO14)
/COL_9: K10.1, K25.1, K42.1, K59.1, K72.1, K85.1, U3.18 (GPIO15)
/COL_10: K11.1, K26.1, K43.1, K60.1, K73.1, K87.1, U3.27 (GPIO16)
/COL_11: K12.1, K27.1, K44.1, K61.1, K74.1, U3.28 (GPIO17)
/COL_12: K13.1, K28.1, K45.1, K62.1, K75.1, U3.29 (GPIO18)
/COL_13: K14.1, K29.1, K46.1, U3.30 (GPIO19)
/COL_14: K15.1, K30.1, K47.1, U3.31 (GPIO20)
/COL_16: K49.1, K86.1, U3.34 (GPIO22)
/GPIO0: D1.1 (K), D2.1 (K), D3.1 (K), D4.1 (K), D5.1 (K), D6.1 (K), D7.1 (K), D8.1 (K), D9.1 (K), D10.1 (K), D11.1 (K), D12.1 (K), D13.1 (K), D14.1 (K), D15.1 (K), D32.1 (K), U3.2 (GPIO0)
/GPIO1: D16.1 (K), D17.1 (K), D18.1 (K), D19.1 (K), D20.1 (K), D21.1 (K), D22.1 (K), D23.1 (K), D24.1 (K), D25.1 (K), D26.1 (K), D27.1 (K), D28.1 (K), D29.1 (K), D30.1 (K), D31.1 (K), D49.1 (K), U3.3 (GPIO1)
/GPIO2: D33.1 (K), D34.1 (K), D35.1 (K), D36.1 (K), D37.1 (K), D38.1 (K), D39.1 (K), D40.1 (K), D41.1 (K), D42.1 (K), D43.1 (K), D44.1 (K), D45.1 (K), D46.1 (K), D47.1 (K), D48.1 (K), D86.1 (K), U3.4 (GPIO2)
/GPIO3: D50.1 (K), D51.1 (K), D52.1 (K), D53.1 (K), D54.1 (K), D55.1 (K), D56.1 (K), D57.1 (K), D58.1 (K), D59.1 (K), D60.1 (K), D61.1 (K), D62.1 (K), U3.5 (GPIO3)
/GPIO4: D63.1 (K), D64.1 (K), D65.1 (K), D66.1 (K), D67.1 (K), D68.1 (K), D69.1 (K), D70.1 (K), D71.1 (K), D72.1 (K), D73.1 (K), D74.1 (K), D75.1 (K), U3.6 (GPIO4)
/GPIO5: D76.1 (K), D77.1 (K), D78.1 (K), D79.1 (K), D80.1 (K), D81.1 (K), D82.1 (K), D83.1 (K), D84.1 (K), D85.1 (K), D87.1 (K), U3.7 (GPIO5)
/QSPI_SCLK: U2.6 (CLK), U3.52 (QSPI_SCLK)
/QSPI_SD0: U2.5 (DI(IO0)), U3.53 (QSPI_SD0)
/QSPI_SD1: U2.2 (DO(IO1)), U3.55 (QSPI_SD1)
/QSPI_SD2: U2.3 (IO2), U3.54 (QSPI_SD2)
/QSPI_SD3: U2.7 (IO3), U3.51 (QSPI_SD3)
/QSPI_SS: R1.1, R2.2, U2.1 (~CS), U3.56 (QSPI_SS)
/RUN: R6.2, U3.26 (RUN)
/USB_D+: J1.A6 (D+), R3.1
/USB_D-: J1.A7 (D-), R4.1
/XIN: C2.1, U3.20 (XIN), Y1.1
/XOUT: R5.1, U3.21 (XOUT)
/~USB_BOOT: JP1.2 (B), R1.2
ENC_1_A: SW11.A, U3.39 (GPIO27_ADC1)
ENC_1_B: SW11.B, U3.38 (GPIO26_ADC0)
ENC_SWA: D32.2 (A), SW11.S2
ENC_SWB: K31.1, K48.1, SW11.S1, U3.32 (GPIO21)
GND: C1.2, C2.2, C3.2, C4.2, C5.2, C6.2, C7.2, C8.2, C9.2, C10.2, C11.2, C12.2, C13.2, C14.2, C15.2, C16.2, C17.2, C18.2, C19.2, C20.2, C21.2, C22.2, C23.2, C24.2, C25.2, J1.A1 (GND), J1.A12 (GND), J1.B1 (GND), J1.B12 (GND), J2.1, JP1.1 (A), JP2.1 (A), LED1.2 (VSS), LED2.2 (VSS), LED3.2 (VSS), LED4.2 (VSS), LED5.2 (VSS), LED6.2 (VSS), LED7.2 (VSS), LED8.2 (VSS), LED9.2 (VSS), LED10.2 (VSS), LED11.2 (VSS), LED12.2 (VSS), LED13.2 (VSS), LED14.2 (VSS), LED15.2 (VSS), LED16.2 (VSS), LED17.2 (VSS), LED18.2 (VSS), LED19.2 (VSS), LED20.2 (VSS), LED21.2 (VSS), LED22.2 (VSS), LED23.2 (VSS), LED24.2 (VSS), LED25.2 (VSS), LED26.2 (VSS), LED27.2 (VSS), LED28.2 (VSS), LED29.2 (VSS), LED30.2 (VSS), LED31.2 (VSS), LED32.2 (VSS), LED33.2 (VSS), LED34.2 (VSS), LED35.2 (VSS), LED36.2 (VSS), LED37.2 (VSS), LED38.2 (VSS), LED39.2 (VSS), LED40.2 (VSS), LED41.2 (VSS), LED42.2 (VSS), LED43.2 (VSS), LED44.2 (VSS), LED45.2 (VSS), LED46.2 (VSS), LED47.2 (VSS), LED48.2 (VSS), LED49.2 (VSS), LED50.2 (VSS), LED51.2 (VSS), LED52.2 (VSS), LED53.2 (VSS), LED54.2 (VSS), LED55.2 (VSS), LED56.2 (VSS), LED57.2 (VSS), LED58.2 (VSS), LED59.2 (VSS), LED60.2 (VSS), LED61.2 (VSS), LED62.2 (VSS), LED63.2 (VSS), LED64.2 (VSS), LED65.2 (VSS), LED66.2 (VSS), LED67.2 (VSS), LED68.2 (VSS), LED69.2 (VSS), LED70.2 (VSS), LED71.2 (VSS), LED72.2 (VSS), LED73.2 (VSS), LED74.2 (VSS), LED75.2 (VSS), LED76.2 (VSS), LED77.2 (VSS), LED78.2 (VSS), LED79.2 (VSS), LED80.2 (VSS), LED81.2 (VSS), LED82.2 (VSS), LED83.2 (VSS), LED84.2 (VSS), LED85.2 (VSS), LED86.2 (VSS), R8.2, R9.2, SW11.C, U1.1 (GND), U2.4 (GND), U3.19 (TESTEN), U3.57 (GND), Y1.2, Y1.4
I2C_SCL: J2.3, U3.37 (GPIO25)
I2C_SDA: J2.4, U3.36 (GPIO24)
LED: LED1.3 (DIN), U3.35 (GPIO23)
LED_OUT_0: LED15.1 (DOUT), LED16.3 (DIN)
LED_OUT_1: LED32.1 (DOUT), LED33.3 (DIN)
LED_OUT_2: LED49.1 (DOUT), LED50.3 (DIN)
LED_OUT_3: LED62.1 (DOUT), LED63.3 (DIN)
LED_OUT_4: LED75.1 (DOUT), LED76.3 (DIN)
unnamed: C3.1, R5.2, Y1.3
unnamed: D1.2 (A), K1.2
unnamed: D2.2 (A), K2.2
unnamed: D3.2 (A), K3.2
unnamed: D4.2 (A), K4.2
unnamed: D5.2 (A), K5.2
unnamed: D6.2 (A), K6.2
unnamed: D7.2 (A), K7.2
unnamed: D8.2 (A), K8.2
unnamed: D9.2 (A), K9.2
unnamed: D10.2 (A), K10.2
unnamed: D11.2 (A), K11.2
unnamed: D12.2 (A), K12.2
unnamed: D13.2 (A), K13.2
unnamed: D14.2 (A), K14.2
unnamed: D15.2 (A), K15.2
unnamed: D16.2 (A), K16.2
unnamed: D17.2 (A), K17.2
unnamed: D18.2 (A), K18.2
unnamed: D19.2 (A), K19.2
unnamed: D20.2 (A), K20.2
unnamed: D21.2 (A), K21.2
unnamed: D22.2 (A), K22.2
unnamed: D23.2 (A), K23.2
unnamed: D24.2 (A), K24.2
unnamed: D25.2 (A), K25.2
unnamed: D26.2 (A), K26.2
unnamed: D27.2 (A), K27.2
unnamed: D28.2 (A), K28.2
unnamed: D29.2 (A), K29.2
unnamed: D30.2 (A), K30.2
unnamed: D31.2 (A), K31.2
unnamed: D33.2 (A), K33.2
unnamed: D34.2 (A), K34.2
unnamed: D35.2 (A), K35.2
unnamed: D36.2 (A), K36.2
unnamed: D37.2 (A), K37.2
unnamed: D38.2 (A), K38.2
unnamed: D39.2 (A), K39.2
unnamed: D40.2 (A), K40.2
unnamed: D41.2 (A), K41.2
unnamed: D42.2 (A), K42.2
unnamed: D43.2 (A), K43.2
unnamed: D44.2 (A), K44.2
unnamed: D45.2 (A), K45.2
unnamed: D46.2 (A), K46.2
unnamed: D47.2 (A), K47.2
unnamed: D48.2 (A), K48.2
unnamed: D49.2 (A), K49.2
unnamed: D50.2 (A), K50.2
unnamed: D51.2 (A), K51.2
unnamed: D52.2 (A), K52.2
unnamed: D53.2 (A), K53.2
unnamed: D54.2 (A), K54.2
unnamed: D55.2 (A), K55.2
unnamed: D56.2 (A), K56.2
unnamed: D57.2 (A), K57.2
unnamed: D58.2 (A), K58.2
unnamed: D59.2 (A), K59.2
unnamed: D60.2 (A), K60.2
unnamed: D61.2 (A), K61.2
unnamed: D62.2 (A), K62.2
unnamed: D63.2 (A), K63.2
unnamed: D64.2 (A), K64.2
unnamed: D65.2 (A), K65.2
unnamed: D66.2 (A), K66.2
unnamed: D67.2 (A), K67.2
unnamed: D68.2 (A), K68.2
unnamed: D69.2 (A), K69.2
unnamed: D70.2 (A), K70.2
unnamed: D71.2 (A), K71.2
unnamed: D72.2 (A), K72.2
unnamed: D73.2 (A), K73.2
unnamed: D74.2 (A), K74.2
unnamed: D75.2 (A), K75.2
unnamed: D76.2 (A), K76.2
unnamed: D77.2 (A), K77.2
unnamed: D78.2 (A), K78.2
unnamed: D79.2 (A), K79.2
unnamed: D80.2 (A), K80.2
unnamed: D81.2 (A), K81.2
unnamed: D82.2 (A), K82.2
unnamed: D83.2 (A), K83.2
unnamed: D84.2 (A), K84.2
unnamed: D85.2 (A), K85.2
unnamed: D86.2 (A), K86.2
unnamed: D87.2 (A), K87.2
unnamed: J1.A5 (CC1), R8.1
unnamed: J1.B5 (CC2), R9.1
unnamed: JP2.2 (B), R6.1
unnamed: LED1.1 (DOUT), LED2.3 (DIN)
unnamed: LED2.1 (DOUT), LED3.3 (DIN)
unnamed: LED3.1 (DOUT), LED4.3 (DIN)
unnamed: LED4.1 (DOUT), LED5.3 (DIN)
unnamed: LED5.1 (DOUT), LED6.3 (DIN)
unnamed: LED6.1 (DOUT), LED7.3 (DIN)
unnamed: LED7.1 (DOUT), LED8.3 (DIN)
unnamed: LED8.1 (DOUT), LED9.3 (DIN)
unnamed: LED9.1 (DOUT), LED10.3 (DIN)
unnamed: LED10.1 (DOUT), LED11.3 (DIN)
unnamed: LED11.1 (DOUT), LED12.3 (DIN)
unnamed: LED12.1 (DOUT), LED13.3 (DIN)
unnamed: LED13.1 (DOUT), LED14.3 (DIN)
unnamed: LED14.1 (DOUT), LED15.3 (DIN)
unnamed: LED16.1 (DOUT), LED17.3 (DIN)
unnamed: LED17.1 (DOUT), LED18.3 (DIN)
unnamed: LED18.1 (DOUT), LED19.3 (DIN)
unnamed: LED19.1 (DOUT), LED20.3 (DIN)
unnamed: LED20.1 (DOUT), LED21.3 (DIN)
unnamed: LED21.1 (DOUT), LED22.3 (DIN)
unnamed: LED22.1 (DOUT), LED23.3 (DIN)
unnamed: LED23.1 (DOUT), LED24.3 (DIN)
unnamed: LED24.1 (DOUT), LED25.3 (DIN)
unnamed: LED25.1 (DOUT), LED26.3 (DIN)
unnamed: LED26.1 (DOUT), LED27.3 (DIN)
unnamed: LED27.1 (DOUT), LED28.3 (DIN)
unnamed: LED28.1 (DOUT), LED29.3 (DIN)
unnamed: LED29.1 (DOUT), LED30.3 (DIN)
unnamed: LED30.1 (DOUT), LED31.3 (DIN)
unnamed: LED31.1 (DOUT), LED32.3 (DIN)
unnamed: LED33.1 (DOUT), LED34.3 (DIN)
unnamed: LED34.1 (DOUT), LED35.3 (DIN)
unnamed: LED35.1 (DOUT), LED36.3 (DIN)
unnamed: LED36.1 (DOUT), LED37.3 (DIN)
unnamed: LED37.1 (DOUT), LED38.3 (DIN)
unnamed: LED38.1 (DOUT), LED39.3 (DIN)
unnamed: LED39.1 (DOUT), LED40.3 (DIN)
unnamed: LED40.1 (DOUT), LED41.3 (DIN)
unnamed: LED41.1 (DOUT), LED42.3 (DIN)
unnamed: LED42.1 (DOUT), LED43.3 (DIN)
unnamed: LED43.1 (DOUT), LED44.3 (DIN)
unnamed: LED44.1 (DOUT), LED45.3 (DIN)
unnamed: LED45.1 (DOUT), LED46.3 (DIN)
unnamed: LED46.1 (DOUT), LED47.3 (DIN)
unnamed: LED47.1 (DOUT), LED48.3 (DIN)
unnamed: LED48.1 (DOUT), LED49.3 (DIN)
unnamed: LED50.1 (DOUT), LED51.3 (DIN)
unnamed: LED51.1 (DOUT), LED52.3 (DIN)
unnamed: LED52.1 (DOUT), LED53.3 (DIN)
unnamed: LED53.1 (DOUT), LED54.3 (DIN)
unnamed: LED54.1 (DOUT), LED55.3 (DIN)
unnamed: LED55.1 (DOUT), LED56.3 (DIN)
unnamed: LED56.1 (DOUT), LED57.3 (DIN)
unnamed: LED57.1 (DOUT), LED58.3 (DIN)
unnamed: LED58.1 (DOUT), LED59.3 (DIN)
unnamed: LED59.1 (DOUT), LED60.3 (DIN)
unnamed: LED60.1 (DOUT), LED61.3 (DIN)
unnamed: LED61.1 (DOUT), LED62.3 (DIN)
unnamed: LED63.1 (DOUT), LED64.3 (DIN)
unnamed: LED64.1 (DOUT), LED65.3 (DIN)
unnamed: LED65.1 (DOUT), LED66.3 (DIN)
unnamed: LED66.1 (DOUT), LED67.3 (DIN)
unnamed: LED67.1 (DOUT), LED68.3 (DIN)
unnamed: LED68.1 (DOUT), LED69.3 (DIN)
unnamed: LED69.1 (DOUT), LED70.3 (DIN)
unnamed: LED70.1 (DOUT), LED71.3 (DIN)
unnamed: LED71.1 (DOUT), LED72.3 (DIN)
unnamed: LED72.1 (DOUT), LED73.3 (DIN)
unnamed: LED73.1 (DOUT), LED74.3 (DIN)
unnamed: LED74.1 (DOUT), LED75.3 (DIN)
unnamed: LED76.1 (DOUT), LED77.3 (DIN)
unnamed: LED77.1 (DOUT), LED78.3 (DIN)
unnamed: LED78.1 (DOUT), LED79.3 (DIN)
unnamed: LED79.1 (DOUT), LED80.3 (DIN)
unnamed: LED80.1 (DOUT), LED81.3 (DIN)
unnamed: LED81.1 (DOUT), LED82.3 (DIN)
unnamed: LED82.1 (DOUT), LED83.3 (DIN)
unnamed: LED83.1 (DOUT), LED84.3 (DIN)
unnamed: LED84.1 (DOUT), LED85.3 (DIN)
unnamed: LED85.1 (DOUT), LED86.3 (DIN)
unnamed: J1.A4 (VBUS), J1.A9 (VBUS), J1.B4 (VBUS), J1.B9 (VBUS), SW1.1 (A)
unnamed: R4.2, U3.46 (USB_DM)
unnamed: R3.2, U3.47 (USB_DP)
VBUS: C1.1, SW1.2 (B), U1.3 (VI)
VCC: C18.1, C19.1, C20.1, C21.1, C22.1, C23.1, C24.1, C25.1, J2.2, LED1.4 (VDD), LED2.4 (VDD), LED3.4 (VDD), LED4.4 (VDD), LED5.4 (VDD), LED6.4 (VDD), LED7.4 (VDD), LED8.4 (VDD), LED9.4 (VDD), LED10.4 (VDD), LED11.4 (VDD), LED12.4 (VDD), LED13.4 (VDD), LED14.4 (VDD), LED15.4 (VDD), LED16.4 (VDD), LED17.4 (VDD), LED18.4 (VDD), LED19.4 (VDD), LED20.4 (VDD), LED21.4 (VDD), LED22.4 (VDD), LED23.4 (VDD), LED24.4 (VDD), LED25.4 (VDD), LED26.4 (VDD), LED27.4 (VDD), LED28.4 (VDD), LED29.4 (VDD), LED30.4 (VDD), LED31.4 (VDD), LED32.4 (VDD), LED33.4 (VDD), LED34.4 (VDD), LED35.4 (VDD), LED36.4 (VDD), LED37.4 (VDD), LED38.4 (VDD), LED39.4 (VDD), LED40.4 (VDD), LED41.4 (VDD), LED42.4 (VDD), LED43.4 (VDD), LED44.4 (VDD), LED45.4 (VDD), LED46.4 (VDD), LED47.4 (VDD), LED48.4 (VDD), LED49.4 (VDD), LED50.4 (VDD), LED51.4 (VDD), LED52.4 (VDD), LED53.4 (VDD), LED54.4 (VDD), LED55.4 (VDD), LED56.4 (VDD), LED57.4 (VDD), LED58.4 (VDD), LED59.4 (VDD), LED60.4 (VDD), LED61.4 (VDD), LED62.4 (VDD), LED63.4 (VDD), LED64.4 (VDD), LED65.4 (VDD), LED66.4 (VDD), LED67.4 (VDD), LED68.4 (VDD), LED69.4 (VDD), LED70.4 (VDD), LED71.4 (VDD), LED72.4 (VDD), LED73.4 (VDD), LED74.4 (VDD), LED75.4 (VDD), LED76.4 (VDD), LED77.4 (VDD), LED78.4 (VDD), LED79.4 (VDD), LED80.4 (VDD), LED81.4 (VDD), LED82.4 (VDD), LED83.4 (VDD), LED84.4 (VDD), LED85.4 (VDD), LED86.4 (VDD)

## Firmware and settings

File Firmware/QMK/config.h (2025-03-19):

#pragma once

#define ENCODER_A_PINS { GP27 }
#define ENCODER_B_PINS { GP26 }

#define ENCODER_RESOLUTION 4
#define ENCODER_SCALING 1
#define NUM_ENCODERS 1

#define BACKLIGHT_PIN GP22
#define BACKLIGHT_BREATHING

#define BACKLIGHT_PWM_DRIVER PWMD5
#define BACKLIGHT_PWM_CHANNEL RP2040_PWM_CHANNEL_A

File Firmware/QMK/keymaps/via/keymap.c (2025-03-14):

// Copyright 2023 QMK
// SPDX-License-Identifier: GPL-2.0-or-later

#include QMK_KEYBOARD_H

const uint16_t PROGMEM keymaps[][MATRIX_ROWS][MATRIX_COLS] = {
    /*
     * ┌───┐   ┌───┬───┬───┬───┐ ┌───┬───┬───┬───┐ ┌───┬───┬───┬───┐ ┌───┬───┬───┐
     * │Esc│   │F1 │F2 │F3 │F4 │ │F5 │F6 │F7 │F8 │ │F9 │F10│F11│F12│ │PSc│Scr│Pse│
     * └───┘   └───┴───┴───┴───┘ └───┴───┴───┴───┘ └───┴───┴───┴───┘ └───┴───┴───┘
     * ┌───┬───┬───┬───┬───┬───┬───┬───┬───┬───┬───┬───┬───┬───────┐ ┌───┬───┬───┐
     * │ ` │ 1 │ 2 │ 3 │ 4 │ 5 │ 6 │ 7 │ 8 │ 9 │ 0 │ - │ = │ Backsp│ │Ins│Hom│PgU│
     * ├───┴─┬─┴─┬─┴─┬─┴─┬─┴─┬─┴─┬─┴─┬─┴─┬─┴─┬─┴─┬─┴─┬─┴─┬─┴─┬─────┤ ├───┼───┼───┤
     * │ Tab │ Q │ W │ E │ R │ T │ Y │ U │ I │ O │ P │ [ │ ] │  \  │ │Del│End│PgD│
     * ├─────┴┬──┴┬──┴┬──┴┬──┴┬──┴┬──┴┬──┴┬──┴┬──┴┬──┴┬──┴┬──┴─────┤ └───┴───┴───┘
     * │ Caps │ A │ S │ D │ F │ G │ H │ J │ K │ L │ ; │ ' │  Enter │
     * ├──────┴─┬─┴─┬─┴─┬─┴─┬─┴─┬─┴─┬─┴─┬─┴─┬─┴─┬─┴─┬─┴─┬─┴────────┤     ┌───┐
     * │ Shift  │ Z │ X │ C │ V │ B │ N │ M │ , │ . │ / │    Shift │     │ ↑ │
     * ├────┬───┴┬──┴─┬─┴───┴───┴───┴───┴───┴──┬┴───┼───┴┬────┬────┤ ┌───┼───┼───┐
     * │Ctrl│GUI │Alt │                        │ Alt│ GUI│Menu│Ctrl│ │ ← │ ↓ │ → │
     * └────┴────┴────┴────────────────────────┴────┴────┴────┴────┘ └───┴───┴───┘
     */
    [0] = LAYOUT_tkl_ansi(
        KC_ESC,           KC_F1,   KC_F2,   KC_F3,   KC_F4,   KC_F5,   KC_F6,   KC_F7,   KC_F8,   KC_F9,   KC_F10,  KC_F11,  KC_F12,     KC_PSCR, KC_SCRL, KC_PAUS,

        KC_GRV,  KC_1,    KC_2,    KC_3,    KC_4,    KC_5,    KC_6,    KC_7,    KC_8,    KC_9,    KC_0,    KC_MINS, KC_EQL,  KC_BSPC,    KC_INS,  KC_HOME, KC_PGUP,
        KC_TAB,  KC_Q,    KC_W,    KC_E,    KC_R,    KC_T,    KC_Y,    KC_U,    KC_I,    KC_O,    KC_P,    KC_LBRC, KC_RBRC, KC_BSLS,    KC_DEL,  KC_END,  KC_PGDN,
        KC_CAPS, KC_A,    KC_S,    KC_D,    KC_F,    KC_G,    KC_H,    KC_J,    KC_K,    KC_L,    KC_SCLN, KC_QUOT,          KC_ENT,
        KC_LSFT,          KC_Z,    KC_X,    KC_C,    KC_V,    KC_B,    KC_N,    KC_M,    KC_COMM, KC_DOT,  KC_SLSH,          KC_RSFT,             KC_UP,
        KC_LCTL, KC_LGUI, KC_LALT,                            KC_SPC,                             KC_RALT, KC_RGUI, KC_APP,  KC_RCTL,    KC_LEFT, KC_DOWN, KC_RGHT
    )
};



#ifdef OLED_ENABLE
bool oled_task_user(void) {
    // Host Keyboard Layer Status
    /*
    oled_write_P(PSTR("Layer: "), false);
    switch (get_highest_layer(layer_state)) {
        case _QWERTY:
            oled_write_P(PSTR("Default\n"), false);
            break;
        case _FN:
            oled_write_P(PSTR("FN\n"), false);
            break;
        case _ADJ:
            oled_write_P(PSTR("ADJ\n"), false);
            break;
        default:
            // Or use the write_ln shortcut over adding '\n' to the end of your string
            oled_write_ln_P(PSTR("Undefined"), false);
    }*/

    // Host Keyboard LED Status
    led_t led_state = host_keyboard_led_state();
    oled_write_P(led_state.num_lock ? PSTR("NUM ") : PSTR("    "), false);
    oled_write_P(led_state.caps_lock ? PSTR("CAP ") : PSTR("    "), false);
    oled_write_P(led_state.scroll_lock ? PSTR("SCR ") : PSTR("    "), false);
    
    return false;
}
#endif

#ifdef ENCODER_MAP_ENABLE
/*
const uint16_t PROGMEM encoder_map[][NUM_ENCODERS][NUM_DIRECTIONS] = {
    [0] = { ENCODER_CCW_CW(MS_WHLU, MS_WHLD),  ENCODER_CCW_CW(KC_VOLD, KC_VOLU)  },
    [1] = { ENCODER_CCW_CW(UG_HUED, UG_HUEU),  ENCODER_CCW_CW(UG_SATD, UG_SATU)  },
    [2] = { ENCODER_CCW_CW(UG_VALD, UG_VALU),  ENCODER_CCW_CW(UG_SPDD, UG_SPDU)  },
    [3] = { ENCODER_CCW_CW(UG_PREV, UG_NEXT),  ENCODER_CCW_CW(KC_RIGHT, KC_LEFT) },
};
*/
const uint16_t PROGMEM encoder_map[][NUM_ENCODERS][NUM_DIRECTIONS] = {
  [0] = { ENCODER_CCW_CW(KC_VOLU, KC_VOLD)},
};
#endif

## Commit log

2025-03-09 add switches
    [deltaboard.kicad_sch]
2025-03-09 rename some labels
    [deltaboard.kicad_sch]
2025-03-11 feat: add switches and leds
    [OLED_0.91_128x32.stp, RP2350_QFN80.step, SK6812MINI-E.step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]
2025-03-11 update footprints
    [deltaboard.kicad_sch]
2025-03-11 feat: place most leds
    [CherryMX.stp, Hotswap_MX.step, deltaboard.kicad_pcb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]
2025-03-12 feat: start routing
    [Stabilizer_MX_2.00u.step, Stabilizer_MX_3.00u.step, Stabilizer_MX_6.00u.step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]
2025-03-13 feat: finish most of the routing
    [deltaboard.kicad_sch]
2025-03-13 chore: move pcb project to PCB/ folder
    [CherryMX.stp, Hotswap_MX.step, OLED_0.91_128x32.stp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]
2025-03-14 feat: add screenshots
    [EC11_Rotary_Encoder_Switched.step]
2025-03-15 finalize pcb design
    [deltaboard.kicad_sch]
2025-03-15 feat: add more mounting holes
    [deltaboard.kicad_sch]
2025-03-15 optimize one more trace
2025-03-15 optimize EVEN MORE TRACES
2025-03-15 generate initial production files
    [BOM-deltaboard.csv, deltaboard.kicad_sch, front plate.step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]
2025-03-15 add hole for oled to front plate
    [front plate.step]
2025-03-15 add BOM.MD
    [deltaboard.kicad_sch]
2025-03-15 fix: set spacebar to 6.25u
    [CPL-deltaboard.csv]
2025-03-15 finish BOM
2025-03-19 fix: make build work and add build artifacts to production folder
    [config.h]
2025-03-19 feat: add deltaboard silkscreen
2025-03-19 feat: brand pcb and case
2025-04-20 chore: add i2c pull up resistors and make vcc traces thicker
    [BOM-deltaboard.csv, deltaboard.kicad_sch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]
2025-04-20 chore: properly connect DN/DP
    [BOM-deltaboard.csv, deltaboard.kicad_sch]
2025-10-08 Add BOM.CSV
    [BOM.CSV]
2025-10-08 Fix formatting issues in BOM.CSV
    [BOM.CSV]
2025-10-08 Add PCB item with cost and shipping details
    [BOM.CSV]
2025-10-08 Update total cost in BOM.MD
2025-10-08 Revise BOM totals and remove itemized costs
    Updated total costs and removed detailed breakdown of components.
2025-10-08 Clarify LCSC Parts description in BOM
    Updated LCSC Parts entry to clarify coverage of MCU and diodes/LEDs.
2025-10-08 Add BOM section to README
    Added a Bill of Materials (BOM) section with details on components, quantities, and costs.
2025-10-09 Replace case image with new render
    Updated the image for the 'Case' section in the README.
2025-10-17 Update BOM with new item and total cost
2025-10-17 Add M3 Standoffs to BOM.CSV
    [BOM.CSV]
2025-10-17 Fix BOM total and add note on standoffs
    Updated total cost in BOM section and added note about standoffs.
2025-10-17 Refactor BOM table and update shipping details
    Updated the BOM table format and corrected shipping notes.
2025-10-17 Revise BOM section in README
    Updated the Bill of Materials (BOM) section with corrected entries and formatting.
